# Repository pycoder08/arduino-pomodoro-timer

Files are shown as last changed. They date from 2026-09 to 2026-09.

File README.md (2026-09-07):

# Arduino Pomodoro Timer

A desktop focus timer I built around an Arduino Mega, a 16x2 LCD, three push buttons, a buzzer, and an RGB LED. It runs configurable focus/break cycles and signals each transition with color and sound.

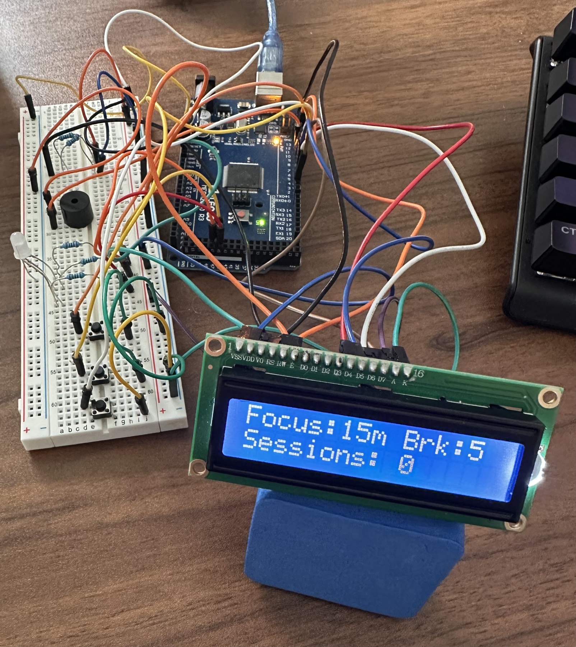
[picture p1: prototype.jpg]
Breadboard prototype with Mega 2560, LCD, buttons, buzzer, and RGB LED


## Status

The breadboard prototype works — I've run the timer through its focus and break cycles on it. The schematic and PCB layout are drawn in KiCad and included here. I'm currently soldering the circuit onto an Arduino protoshield.

I have not fabricated the custom PCB yet, so the layout is a work in progress rather than something I'd send to a fab house today. Routing and design-rule checks still need a pass.

## Features

- Three focus/break presets: 25/5, 15/5, and 50/10 minutes
- Start, pause, and resume, with the remaining time preserved across a pause
- Tap Reset to skip to the next phase; hold it for a second to cancel the session outright
- Preset selection with the mode button while idle, remembered in EEPROM across power cycles
- Count of sessions finished since power-on, shown on the idle screen
- Countdown on a 16x2 LCD
- Red RGB LED breathing during focus, solid green during breaks
- Multi-note buzzer melodies at session transitions

Button handling, the melodies, and the LED breathing are all non-blocking, so the countdown
stays accurate and the buttons stay responsive no matter what else is happening.

## Hardware

Arduino Mega 2560, 16x2 LCD, three push buttons, a passive buzzer, a common-cathode RGB LED,
resistors, breadboard, and jumper wire. LCD contrast comes from a fixed divider (roughly 8.5k to
5V and 1k to ground) rather than a trim potentiometer, so no pin is spent on it.

The sketch drives the RGB LED on pins 44–46. Those are PWM-capable on the Mega, which the
breathing effect needs, and they don't exist on a Uno — remap them if you build this on a smaller
board. I still need to document exact component models and resistor values.

### Pin assignments

| Function | Arduino pin |
| --- | --- |
| LCD RS | 12 |
| LCD enable | 11 |
| LCD D4–D7 | 5, 4, 3, 2 |
| Start / pause | 6 |
| Reset | 7 |
| Mode | 8 |
| Buzzer | 9 |
| RGB red | 44 |
| RGB blue | 45 |
| RGB green | 46 |

Buttons are wired active-low using `INPUT_PULLUP` and are debounced in software. This table covers
the software pin assignment only — check LCD contrast wiring, your RGB LED's common pin, and
current-limiting resistors against your own build.

## Running it

1. Open `timer.ino` in the Arduino IDE, letting it create the enclosing `timer` folder if prompted.
2. Make sure the `LiquidCrystal` library is installed. `EEPROM` ships with the IDE.
3. Select your board and port, confirming the pins above exist on it.
4. Compile and upload.

## KiCad files

`Timer.kicad_pro` is the main project, with `Timer.kicad_sch` for the schematic and `Timer.kicad_pcb` for the layout. `Arduino_MountingHole.pretty` holds the custom mounting-hole footprints the board references.

`focus_timer_schematic.kicad_sch` is an earlier sheet covering just the Arduino header connections, kept for reference.

## A note on the code

I wrote this project's firmware with AI assistance. The circuit design, breadboard build and testing, schematic capture, PCB layout, and protoshield assembly are my own work.

## To do

- Finish the protoshield soldering and retest every control
- Document component models and resistor values
- Run design-rule checks on the PCB before fabricating
- Test all three presets, pause/resume in both phases, tap and hold Reset, and the full
  focus-to-break transition
- Persist the session count across power cycles, or roll it over on a real clock rather than at
  power-on

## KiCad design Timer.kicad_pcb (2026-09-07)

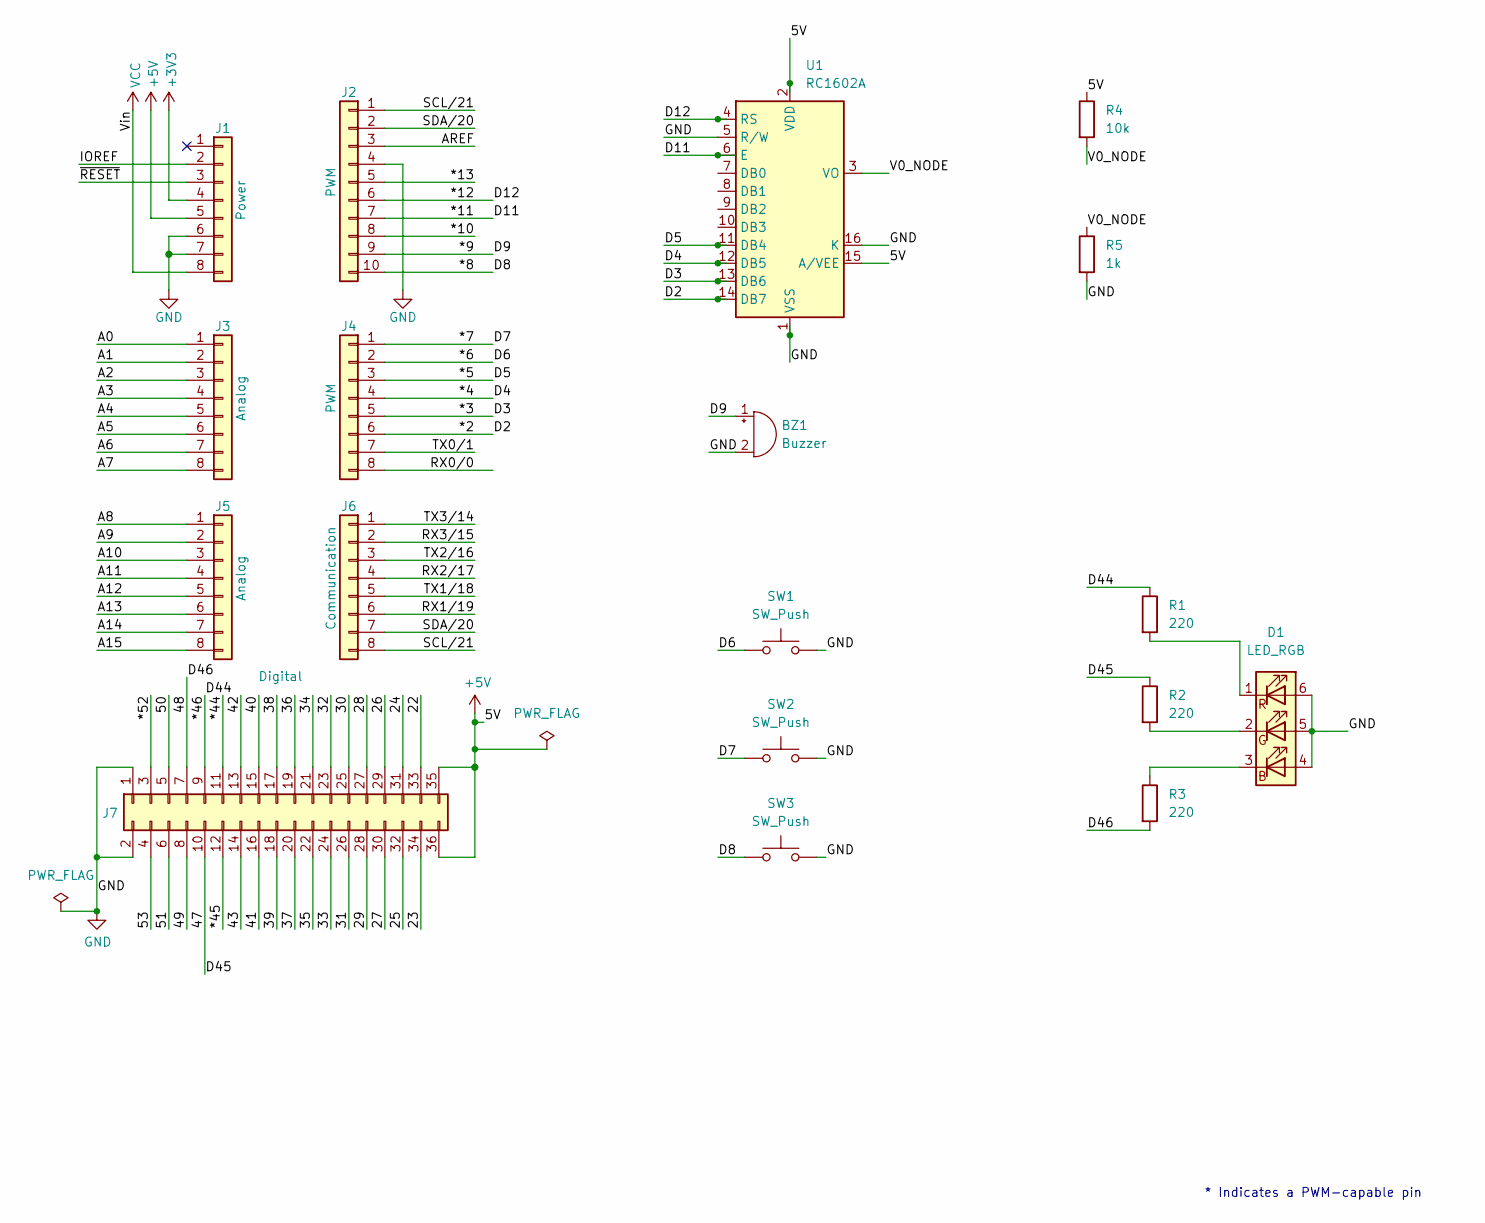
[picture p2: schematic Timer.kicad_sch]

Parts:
BZ1: Buzzer; MagneticBuzzer_ProSignal_ABT-410-RC
D1: LED_RGB; LED_RGB_5050-6
J1: Power; PinSocket_1x08_P2.54mm_Vertical
J2: PWM; PinSocket_1x10_P2.54mm_Vertical
J3, J5: Analog; PinSocket_1x08_P2.54mm_Vertical
J4: PWM; PinSocket_1x08_P2.54mm_Vertical
J6: Communication; PinSocket_1x08_P2.54mm_Vertical
J7: Digital; PinSocket_2x18_P2.54mm_Vertical
R1, R2, R3: 220; R_Axial_DIN0207_L6.3mm_D2.5mm_P10.16mm_Horizontal
R4: 10k; R_Axial_DIN0207_L6.3mm_D2.5mm_P10.16mm_Horizontal
R5: 1k; R_Axial_DIN0207_L6.3mm_D2.5mm_P10.16mm_Horizontal
SW1, SW2, SW3: SW_Push; SW_PUSH_6mm
U1: RC1602A

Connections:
+3V3: J1.4
+5V: J1.5, J7.35, J7.36, R4.1, U1.2 (VDD), U1.15 (A/VEE)
/22: J7.33
/23: J7.34
/24: J7.31
/25: J7.32
/26: J7.29
/27: J7.30
/28: J7.27
/29: J7.28
/30: J7.25
/31: J7.26
/32: J7.23
/33: J7.24
/34: J7.21
/35: J7.22
/36: J7.19
/37: J7.20
/38: J7.17
/39: J7.18
/40: J7.15
/41: J7.16
/42: J7.13
/43: J7.14
/47: J7.10, R2.1
/48: J7.7, R3.2
/49: J7.8
/50: J7.5
/51: J7.6
/53: J7.4
/*2: J4.6, U1.14 (DB7)
/*3: J4.5, U1.13 (DB6)
/*4: J4.4, U1.12 (DB5)
/*5: J4.3, U1.11 (DB4)
/*6: J4.2, SW1.1
/*7: J4.1, SW2.1
/*8: J2.10, SW3.1
/*9: BZ1.1 (+), J2.9
/*10: J2.8
/*11: J2.7, U1.6 (E)
/*12: J2.6, U1.4 (RS)
/*13: J2.5
/*44: J7.11
/*45: J7.12
/*46: J7.9, R1.1
/*52: J7.3
/A0: J3.1
/A1: J3.2
/A2: J3.3
/A3: J3.4
/A4: J3.5
/A5: J3.6
/A6: J3.7
/A7: J3.8
/A8: J5.1
/A9: J5.2
/A10: J5.3
/A11: J5.4
/A12: J5.5
/A13: J5.6
/A14: J5.7
/A15: J5.8
/AREF: J2.3
/IOREF: J1.2
/RX0/0: J4.8
/RX1/19: J6.6
/RX2/17: J6.4
/RX3/15: J6.2
/SCL/21: J2.1, J6.8
/SDA/20: J2.2, J6.7
/TX0/1: J4.7
/TX1/18: J6.5
/TX2/16: J6.3
/TX3/14: J6.1
/V0_NODE: R4.2, R5.1, U1.3 (VO)
/~RESET: J1.3
GND: BZ1.2 (-), D1.4 (BA), D1.5 (GA), D1.6 (RA), J1.6, J1.7, J2.4, J7.1, J7.2, R5.2, SW1.2, SW2.2, SW3.2, U1.1 (VSS), U1.5 (R/W), U1.16 (K)
unnamed: D1.3 (BK), R3.1
unnamed: D1.2 (GK), R2.2
unnamed: D1.1 (RK), R1.2
VCC: J1.8

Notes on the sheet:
* Indicates a PWM-capable pin

Board: 2 copper layers, 24 parts (0 on the bottom side), 21 nets, no tracks yet.

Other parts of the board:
MH1, MH2, MH3, MH4, MH5, MH6: MountingHole_3.2mm

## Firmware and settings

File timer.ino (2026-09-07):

/*
  Desktop Focus Timer
  Arduino Mega 2560

  Hardware:
    LCD1602 (4-bit mode)      -> pins 12(RS),11(E),5(D4),4(D5),3(D6),2(D7)
    Start/Pause button        -> pin 6  (INPUT_PULLUP)
    Reset button               -> pin 7  (INPUT_PULLUP)
    Mode button                -> pin 8  (INPUT_PULLUP)
    Passive buzzer              -> pin 9
    RGB LED (common cathode)   -> R=44, G=46, B=45
    LCD contrast (V0)          -> fixed resistor divider (~8.5k to 5V, ~1k to GND) - no pin used

  Behavior:
    IDLE          -> LCD shows focus/break lengths + sessions completed today,
                     cycle options with Mode, press Start to begin
    RUNNING_FOCUS -> red LED (slow breathing effect), countdown, auto-advances to break when done
    RUNNING_BREAK -> green LED (solid), countdown, auto-returns to IDLE when done
    PAUSED        -> Start/Pause resumes with remaining time saved
    Reset (tap, on release) -> skips to the next phase
    Reset (held 1s+)    -> full reset back to IDLE, cancels current session

  Last-used session option is saved to EEPROM and restored on power-up.
  Session counter resets on power-up (not saved, since it's meant to track "today").
*/

#include <LiquidCrystal.h>
#include <EEPROM.h>

LiquidCrystal lcd(12, 11, 5, 4, 3, 2);

const int startPin = 6;
const int resetPin = 7;
const int modePin = 8;
const int buzzerPin = 9;
const int redPin = 44;
const int greenPin = 46; // physical wiring swap accounted for
const int bluePin = 45;  // physical wiring swap accounted for

const unsigned long DEBOUNCE_MS = 50;
const unsigned long REPEAT_LOCKOUT_MS = 200;
const unsigned long LONG_PRESS_MS = 1000; // hold Reset this long for a full reset
const int EEPROM_OPTION_ADDR = 0;

enum State { IDLE, RUNNING_FOCUS, RUNNING_BREAK, PAUSED };
State currentState = IDLE;

const int focusOptions[] = {25, 15, 50};
const int breakOptions[] = {5, 5, 10};
const int NUM_OPTIONS = 3;
int optionIndex = 0;
int sessionsCompleted = 0;

unsigned long sessionLengthMs;
unsigned long startTime;
unsigned long remainingMs;
bool wasFocusBeforePause = true;

// ---- non-blocking debounce state ----
struct Button {
  int pin;
  bool lastReading;
  bool stableState;
  unsigned long lastChangeTime;
  unsigned long lastAcceptedTime;
  bool longPressFired;
  bool pressPending;   // a press is down and has not yet resolved to short or long
};

Button startBtn = {startPin, HIGH, HIGH, 0, 0, false, false};
Button resetBtn = {resetPin, HIGH, HIGH, 0, 0, false, false};
Button modeBtn  = {modePin,  HIGH, HIGH, 0, 0, false, false};

// returns true exactly once, the moment a debounced press (HIGH->LOW) is accepted
bool checkPressed(Button &b) {
  bool reading = digitalRead(b.pin);
  unsigned long now = millis();

  if (reading != b.lastReading) {
    b.lastChangeTime = now;
    b.lastReading = reading;
  }

  if ((now - b.lastChangeTime) > DEBOUNCE_MS && b.stableState != reading) {
    b.stableState = reading;
    if (b.stableState == LOW && (now - b.lastAcceptedTime) > REPEAT_LOCKOUT_MS) {
      b.lastAcceptedTime = now;
      b.longPressFired = false;
      b.pressPending = true;
      return true;
    }
  }
  return false;
}

// returns true exactly once, when a currently-held button crosses the long-press threshold
bool checkLongPress(Button &b) {
  if (b.stableState == LOW && !b.longPressFired) {
    if (millis() - b.lastChangeTime > LONG_PRESS_MS) {
      b.longPressFired = true;
      b.pressPending = false; // this press is a hold, so cancel the pending tap
      return true;
    }
  }
  return false;
}

// returns true once on release, but only if the press never became a long press
bool checkTap(Button &b) {
  if (b.stableState == HIGH && b.pressPending) {
    b.pressPending = false;
    return true;
  }
  return false;
}

// ---- non-blocking buzzer melody player ----
int melodyNotes[8];
int melodyDurations[8];
int melodyLength = 0;
int melodyIndex = 0;
unsigned long melodyNoteStart = 0;
bool melodyPlaying = false;

void playMelody(int *notes, int *durations, int length) {
  for (int i = 0; i < length; i++) {
    melodyNotes[i] = notes[i];
    melodyDurations[i] = durations[i];
  }
  melodyLength = length;
  melodyIndex = 0;
  melodyPlaying = true;
  melodyNoteStart = millis();
  tone(buzzerPin, melodyNotes[0], melodyDurations[0]);
}

void updateMelody() {
  if (!melodyPlaying) return;
  if (millis() - melodyNoteStart >= (unsigned long)melodyDurations[melodyIndex] + 30) {
    melodyIndex++;
    if (melodyIndex >= melodyLength) {
      melodyPlaying = false;
      return;
    }
    melodyNoteStart = millis();
    tone(buzzerPin, melodyNotes[melodyIndex], melodyDurations[melodyIndex]);
  }
}

// ---- non-blocking breathing LED (red channel pulse during focus) ----
unsigned long breatheStart = 0;
const unsigned long BREATHE_PERIOD_MS = 3000;

void updateBreathingRed() {
  unsigned long t = (millis() - breatheStart) % BREATHE_PERIOD_MS;
  float phase = (float)t / BREATHE_PERIOD_MS; // 0..1
  float level = (1.0 - cos(phase * 2.0 * PI)) / 2.0; // 0..1 smooth pulse
  int brightness = 60 + (int)(level * 195); // floor at 60 so it never fully goes dark
  analogWrite(redPin, brightness);
  analogWrite(greenPin, 0);
  analogWrite(bluePin, 0);
}

void setup() {
  Serial.begin(9600);
  pinMode(startPin, INPUT_PULLUP);
  pinMode(resetPin, INPUT_PULLUP);
  pinMode(modePin, INPUT_PULLUP);
  pinMode(buzzerPin, OUTPUT);
  pinMode(redPin, OUTPUT);
  pinMode(greenPin, OUTPUT);
  pinMode(bluePin, OUTPUT);

  int savedOption = EEPROM.read(EEPROM_OPTION_ADDR);
  if (savedOption >= 0 && savedOption < NUM_OPTIONS) {
    optionIndex = savedOption;
  }

  lcd.begin(16, 2);
  lcd.print("Focus Timer");
  delay(1000);
  showIdleScreen();
}

void loop() {
  bool startPressed = checkPressed(startBtn);
  checkPressed(resetBtn); // keeps reset's debounce state current; it acts on release
  bool modePressed  = checkPressed(modeBtn);
  bool resetLongPress = checkLongPress(resetBtn);
  bool resetTapped = checkTap(resetBtn);

  updateMelody();

  if (resetLongPress) {
    // full reset, cancels whatever was happening
    currentState = IDLE;
    setColor(0, 0, 0);
    tone(buzzerPin, 300, 200);
    showIdleScreen();
  } else if (resetTapped && currentState != IDLE) {
    // tap while running/paused: skip to next phase
    skipToNextPhase();
  } else if (resetTapped && currentState == IDLE) {
    // tap while idle: just a gentle no-op beep, nothing to skip
    tone(buzzerPin, 400, 80);
  }

  if (modePressed && currentState == IDLE) {
    optionIndex = (optionIndex + 1) % NUM_OPTIONS;
    EEPROM.update(EEPROM_OPTION_ADDR, optionIndex);
    showIdleScreen();
  }

  if (startPressed) {
    handleStartPause();
  }

  if (currentState == RUNNING_FOCUS || currentState == RUNNING_BREAK) {
    updateCountdown();
    if (currentState == RUNNING_FOCUS) {
      updateBreathingRed();
    }
  }
}

void handleStartPause() {
  if (currentState == IDLE) {
    beginFocusSession();
  } else if (currentState == RUNNING_FOCUS || currentState == RUNNING_BREAK) {
    unsigned long elapsed = millis() - startTime;
    remainingMs = (elapsed < sessionLengthMs) ? (sessionLengthMs - elapsed) : 0;
    wasFocusBeforePause = (currentState == RUNNING_FOCUS);
    currentState = PAUSED;
    setColor(0, 0, 0);
    tone(buzzerPin, 600, 150);
    lcd.setCursor(0, 0);
    lcd.print("PAUSED          ");
  } else if (currentState == PAUSED) {
    sessionLengthMs = remainingMs;
    startTime = millis();
    currentState = wasFocusBeforePause ? RUNNING_FOCUS : RUNNING_BREAK;
    if (wasFocusBeforePause) {
      breatheStart = millis();
    } else {
      setColor(0, 255, 0);
    }
    tone(buzzerPin, 1000, 150);
  }
}

void beginFocusSession() {
  sessionLengthMs = (unsigned long)focusOptions[optionIndex] * 60000UL;
  startTime = millis();
  currentState = RUNNING_FOCUS;
  breatheStart = millis();
  tone(buzzerPin, 1000, 150);
}

void beginBreakSession() {
  sessionLengthMs = (unsigned long)breakOptions[optionIndex] * 60000UL;
  startTime = millis();
  currentState = RUNNING_BREAK;
  setColor(0, 255, 0);
}

// short-press Reset while running: jump straight to the next phase
void skipToNextPhase() {
  bool inFocus = (currentState == RUNNING_FOCUS) ||
                 (currentState == PAUSED && wasFocusBeforePause);
  if (inFocus) {
    sessionsCompleted++;
    beginBreakSession();
    tone(buzzerPin, 800, 100);
  } else {
    currentState = IDLE;
    setColor(0, 0, 0);
    tone(buzzerPin, 500, 150);
    showIdleScreen();
  }
}

void updateCountdown() {
  unsigned long elapsed = millis() - startTime;
  long remaining = sessionLengthMs - elapsed;

  if (remaining <= 0) {
    if (currentState == RUNNING_FOCUS) {
      sessionsCompleted++;
      beginBreakSession();
      int notes[] = {880, 988, 1175};
      int durs[]  = {100, 100, 150};
      playMelody(notes, durs, 3);
    } else {
      currentState = IDLE;
      setColor(0, 0, 0);
      int notes[] = {1175, 988, 784, 1047};
      int durs[]  = {100, 100, 100, 250};
      playMelody(notes, durs, 4);
      showIdleScreen();
    }
    return;
  }

  int totalSeconds = remaining / 1000;
  int mins = totalSeconds / 60;
  int secs = totalSeconds % 60;

  lcd.setCursor(0, 0);
  lcd.print(currentState == RUNNING_FOCUS ? "FOCUS           " : "BREAK           ");
  lcd.setCursor(0, 1);
  if (mins < 10) lcd.print("0");
  lcd.print(mins);
  lcd.print(":");
  if (secs < 10) lcd.print("0");
  lcd.print(secs);
  lcd.print("        ");
}

void showIdleScreen() {
  lcd.clear();
  lcd.setCursor(0, 0);
  lcd.print("Focus:");
  lcd.print(focusOptions[optionIndex]);
  lcd.print("m Brk:");
  lcd.print(breakOptions[optionIndex]);
  lcd.setCursor(0, 1);
  lcd.print("Sessions: ");
  lcd.print(sessionsCompleted);
}

void setColor(int r, int g, int b) {
  analogWrite(redPin, r);
  analogWrite(greenPin, g);
  analogWrite(bluePin, b);
}

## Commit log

2026-09-07 Add timer firmware and KiCad project
    [Timer.kicad_pcb, Timer.kicad_sch, focus_timer_schematic.kicad_sch]
2026-09-07 Add breadboard prototype photo
2026-09-07 Add missing Arduino_MountingHole footprint library
    fp-lib-table referenced ${KIPRJMOD}/Arduino_MountingHole.pretty, but the
    library was never included, so the mounting-hole footprints could not be
    edited or re-linked from the PCB.
2026-09-07 Update firmware: session counter, EEPROM presets, tap/hold reset
    - Track and display sessions completed since power-on
    - Persist the selected focus/break preset to EEPROM
    - Tap Reset to skip a phase, hold 1s to cancel the session
    - Breathing red LED during focus, solid green on break
    - Replace blocking delay() debounce with non-blocking button state
    - Non-blocking multi-note melodies at session transitions
    - Record the phase at pause time so resume returns to the correct one
    [timer.ino]
2026-09-07 Fix Reset hold firing the phase-skip before the cancel
    checkPressed() fires on the press edge, so holding Reset ran skipToNextPhase()
    immediately and only cancelled a second later. During focus that incremented
    sessionsCompleted, banking a session that was never finished, and sounded the
    skip tone before the reset tone.
    Reset now resolves on release: a hold clears the pending tap so the skip never
    runs. Start and Mode still fire on press, having no hold behaviour.
    Also corrects the header comment, which listed G=45/B=46 while the code has
    greenPin=46 and bluePin=45. The code matches the wiring.
    [timer.ino]
2026-09-07 Rewrite README in the author's voice and match current firmware
    Documents the session counter, EEPROM preset memory, tap/hold reset and
    breathing LED. Corrects the hardware list: LCD contrast now comes from a
    fixed divider rather than a potentiometer. Notes that pins 44-46 are PWM
    capable on the Mega, which the breathing effect requires.
